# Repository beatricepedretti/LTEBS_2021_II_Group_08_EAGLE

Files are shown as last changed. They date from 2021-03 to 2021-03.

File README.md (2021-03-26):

# LTEBS_2021_II_Group_08_EAGLE

This repository contains the first project for the Electronic Technologies and Biosensors Laboratory course, part of the Biomedical Engineering MSc at Politecnico di Milano.
In this project we designed a schematic, a PCB and two custom components using Autodesk EAGLE. The aim of the work was to design a PCB embedding the PSoC 5LP micro-controller in order to evaluate its performance.

# PCB relevant info

- The PCB manufacturer is MDSrl and therefore we followed the rules explained on their website for PCB design (https://www.mdpcb.com/mddesignrules.html).
the 10mil minimum track width requested in the assignment specifications caused clearance errors at the pins of the MUX, therefore we routed this component using 8mil wires while still using 10mils wires everywhere else. This choice satisfies the manufacturer requirements which report 6mils as the minimum width for traces.
- We positioned the light sensor as far away as possible from the LED in order to avoid luminous interference given by the LED. We also tried to position the light sensor as isolated as possible from "tall" components in order to avoid shadows that could interfere with the sensor's measurements.
- We positioned the temperature sensor as far away as possible from the power supply in order to avoid interference given by possible heating of the power supply.
- For the copper pour we used isolation 8 that is the minimum allowed by the manufacturer
- We put jumpers on side of the board

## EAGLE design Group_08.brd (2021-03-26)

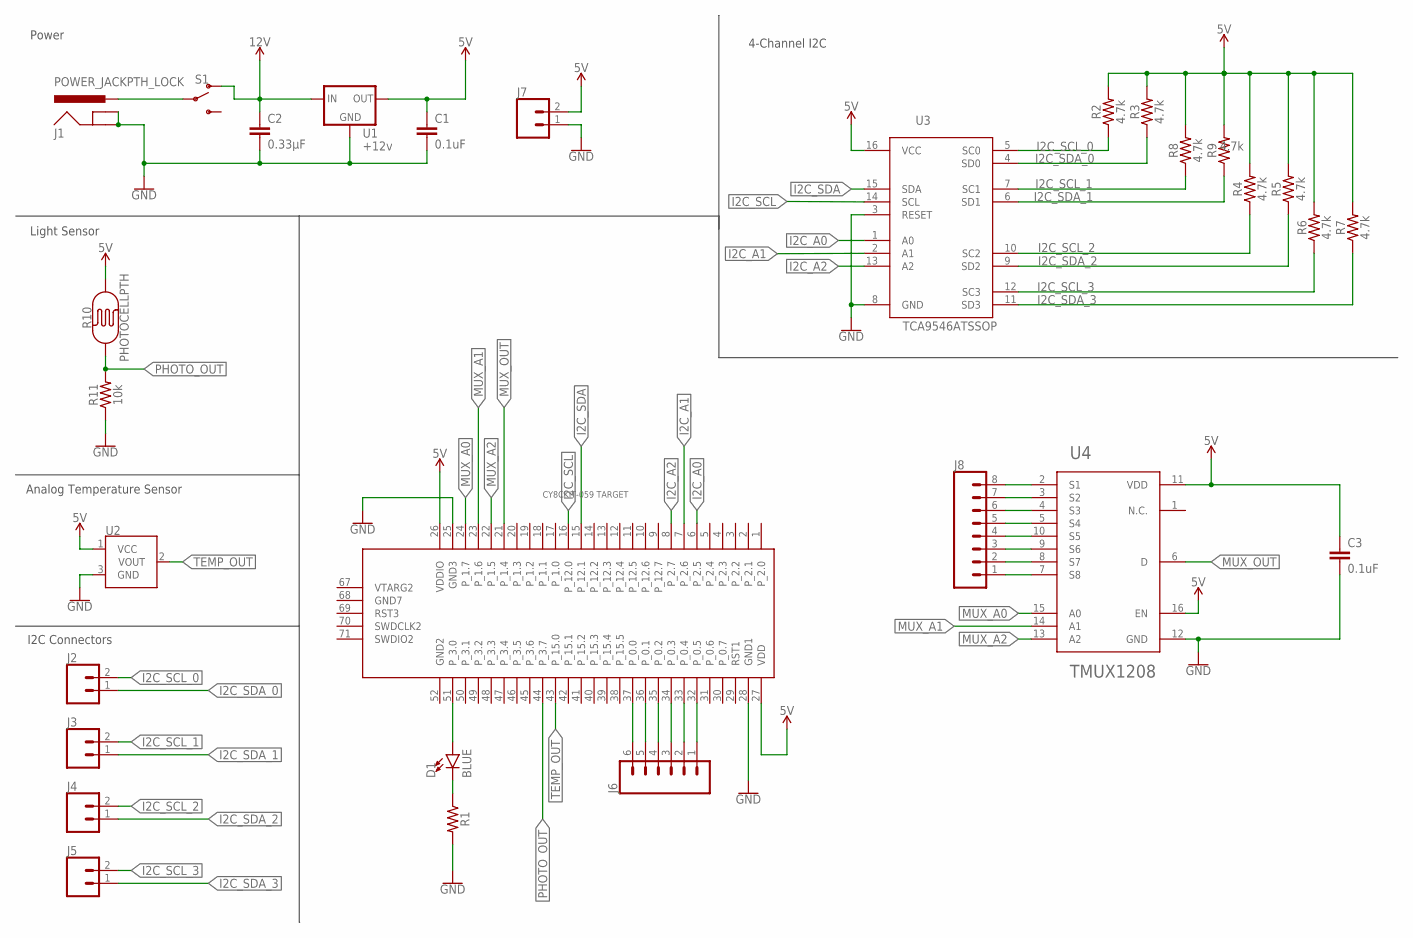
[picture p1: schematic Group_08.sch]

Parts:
C1, C3: 0.1uF; CAP-PTH-SMALL-KIT
C2: 0.33µF; 0805
CY8CKIT059-TARGET: CY8CKIT-059_TARGET
D1: BLUE; LED-1206
J1: POWER_JACKPTH_LOCK; POWER_JACK_PTH_LOCK
J2, J3, J4, J5, J7: CONN_02; 1X02
J6: CONN_06LOCK; 1X06_LOCK
J8: CONN_08LOCK; 1X08_LOCK
R1: RESISTORAXIAL-0.3; AXIAL-0.3
R2, R3, R4, R5, R6, R7, R8, R9: 4.7k; 0603
R10: PHOTOCELLPTH; PHOTOCELL
R11: 10k; 0603
S1: SWITCH-SPDT-PTH-11.6X4.0MM; SWITCH_SPDT_PTH_11.6X4.0MM
U1: +12v; TO-252
U2: TMP36GT9; TO-92
U3: TCA9546ATSSOP; TSSOP16
U4: TMUX1208; QFN16

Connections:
5V: C1.1, C3.1, CY8CKIT059-TARGET.26 (VDDIO), CY8CKIT059-TARGET.27 (VDD), J7.2, R2.2, R3.2, R4.2, R5.2, R6.2, R7.2, R8.2, R9.2, R10.2, U1.2 (OUT), U2.1 (VCC), U3.16 (VCC), U4.11 (VDD), U4.16 (EN)
12V: C2.1, S1.1 (O), U1.1 (IN)
GND: C1.2, C2.2, C3.2, CY8CKIT059-TARGET.25 (GND3), CY8CKIT059-TARGET.28 (GND1), J1.GND, J1.GNDBREAK, J7.1, R1.P$2 (2), R11.1, U1.3 (GND), U2.3 (GND), U3.3 (RESET), U3.8 (GND), U4.12 (GND)
I2C_A0: CY8CKIT059-TARGET.6 (P_2.5), U3.1 (A0)
I2C_A1: CY8CKIT059-TARGET.7 (P_2.6), U3.2 (A1)
I2C_A2: CY8CKIT059-TARGET.8 (P_2.7), U3.13 (A2)
I2C_SCL: CY8CKIT059-TARGET.16 (P_12.0), U3.14 (SCL)
I2C_SCL_0: J2.2, R2.1, U3.5 (SC0)
I2C_SCL_1: J3.2, R8.1, U3.7 (SC1)
I2C_SCL_2: J4.2, R4.1, U3.10 (SC2)
I2C_SCL_3: J5.2, R6.1, U3.12 (SC3)
I2C_SDA: CY8CKIT059-TARGET.15 (P_12.1), U3.15 (SDA)
I2C_SDA_0: J2.1, R3.1, U3.4 (SD0)
I2C_SDA_1: J3.1, R9.1, U3.6 (SD1)
I2C_SDA_2: J4.1, R5.1, U3.9 (SD2)
I2C_SDA_3: J5.1, R7.1, U3.11 (SD3)
MUX_A0: CY8CKIT059-TARGET.24 (P_1.7), U4.15 (A0)
MUX_A1: CY8CKIT059-TARGET.23 (P_1.6), U4.14 (A1)
MUX_A2: CY8CKIT059-TARGET.22 (P_1.5), U4.13 (A2)
MUX_OUT: CY8CKIT059-TARGET.21 (P_1.4), U4.6 (D)
unnamed: J1.PWR, S1.2
unnamed: J8.1, U4.7 (S8)
unnamed: J8.2, U4.8 (S7)
unnamed: J8.3, U4.9 (S6)
unnamed: J8.4, U4.10 (S5)
unnamed: J8.5, U4.5 (S4)
unnamed: J8.6, U4.4 (S3)
unnamed: J8.7, U4.3 (S2)
unnamed: J8.8, U4.2 (S1)
unnamed: CY8CKIT059-TARGET.37 (P_0.0), J6.6
unnamed: CY8CKIT059-TARGET.32 (P_0.5), J6.1
unnamed: CY8CKIT059-TARGET.33 (P_0.4), J6.2
unnamed: CY8CKIT059-TARGET.34 (P_0.3), J6.3
unnamed: CY8CKIT059-TARGET.35 (P_0.2), J6.4
unnamed: CY8CKIT059-TARGET.36 (P_0.1), J6.5
unnamed: D1.C, R1.P$1 (1)
unnamed: CY8CKIT059-TARGET.51 (P_3.0), D1.A
PHOTO_OUT: CY8CKIT059-TARGET.44 (P_3.7), R10.1, R11.2
TEMP_OUT: CY8CKIT059-TARGET.43 (P_15.0), U2.2 (VOUT)

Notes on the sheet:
Light Sensor
Analog Temperature Sensor
Power
4-Channel I2C
I2C Connectors

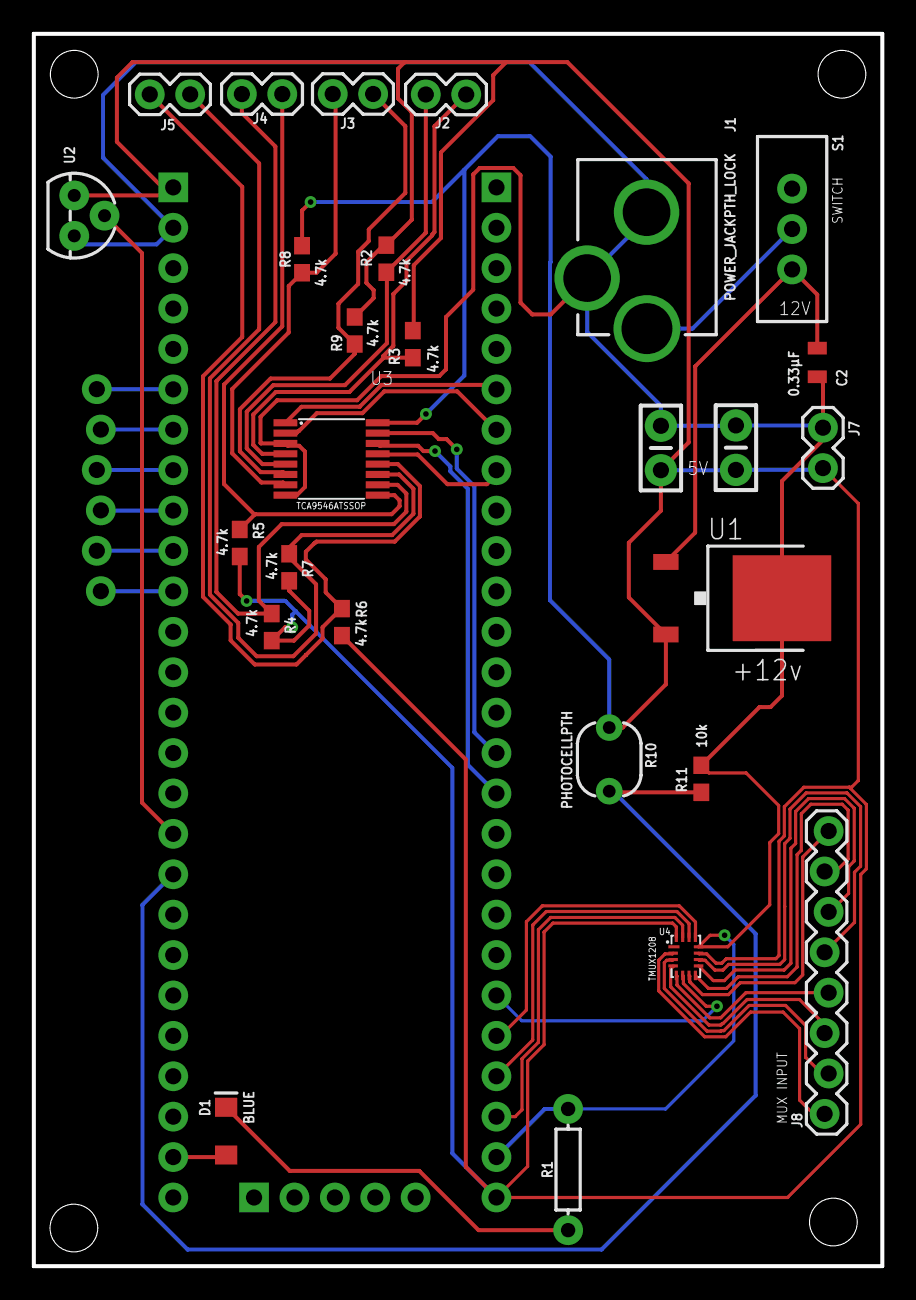
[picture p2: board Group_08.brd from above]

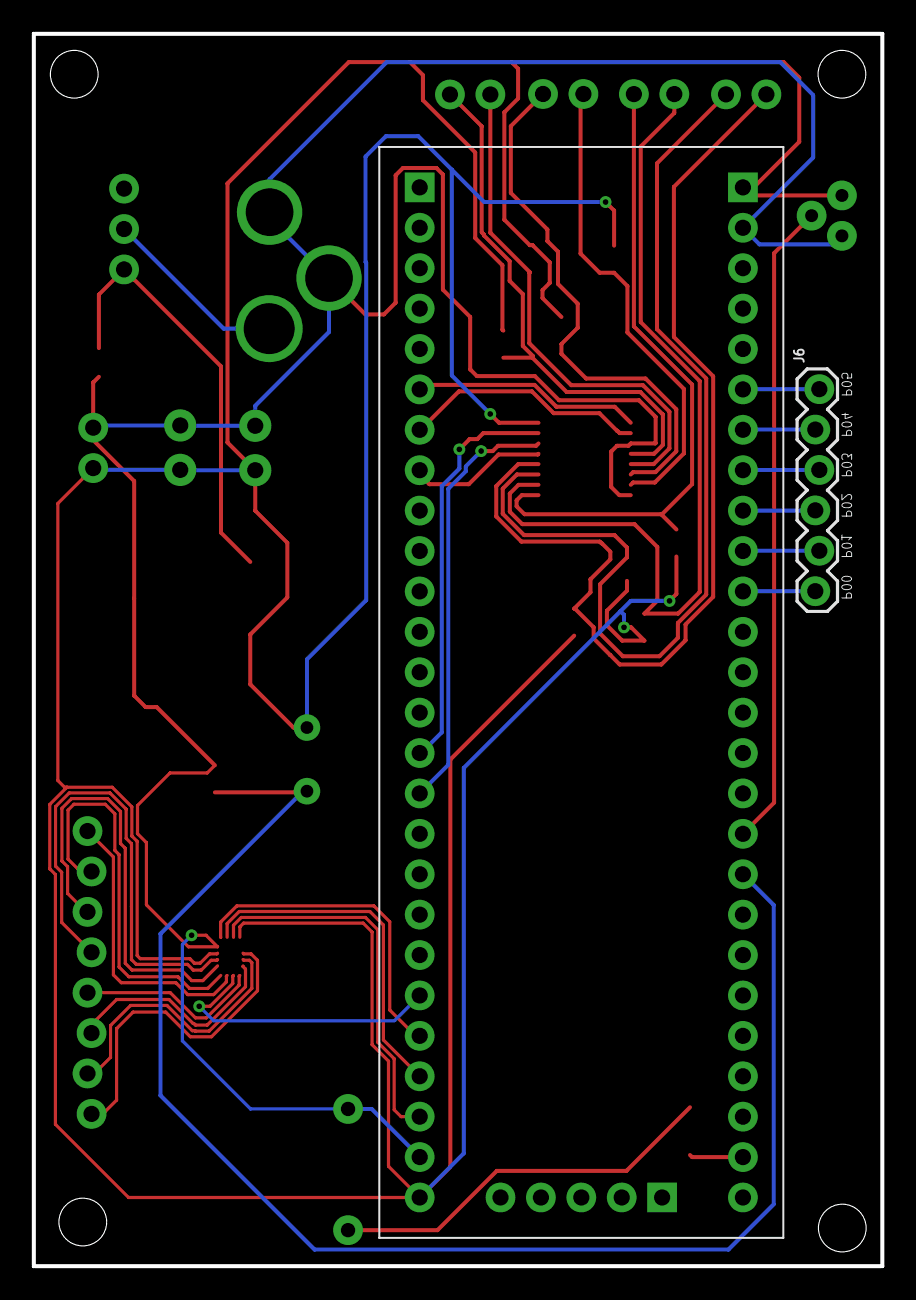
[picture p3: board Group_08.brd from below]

Board: 2 copper layers, 53.3 x 77.5 mm, 29 parts (2 on the bottom side), 39 nets.

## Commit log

2021-03-19 Added TMUX1208 device to general library ('Group_08_Library.lbr') for the moment. Saved the device in an additional library ('TMUX1208.lbr') for safety.
2021-03-19 Modified symbol to match reference schematics
2021-03-20 Adjusted TMUX1208 footprint
2021-03-22 Modified description headline of device
2021-03-22 First schematic prototype. Need to adjust nets
    [Group_08.sch]
2021-03-24 completed wiring
    [Group_08.sch]
2021-03-24 no changes, used correct username
    [Group_08.sch]
2021-03-24 Fixed wiring and did small aesthetic adjustments to library symbols
    [Group_08.sch]
2021-03-25 board with almoost all wiring done
    [Group_08.sch]
2021-03-25 real board file
    [Group_08.brd]
2021-03-25 Alternative version; 0 errors. Already done all wiring and copper pour. Need to add silkscreen and it's possible to reduce board size.
    [Group_08_alternative.brd, Group_08_alternative.sch]
2021-03-25 Mia versione della board
    [Group_08_Chiara.brd]
2021-03-25 added silkscreen
    [Group_08_Chiara.brd]
2021-03-25 Optimized board, added silkscreen. 0 errors after performing DCR.
    [Group_08_alternative.brd, Group_08_alternative.sch]
2021-03-25 Deleted original prototypes and updated file names
    [Group_08.brd, Group_08.sch]
2021-03-25 Deleted old files
    [Group_08_alternative.brd, Group_08_alternative.sch]
2021-03-26 minor adjustments at wire positioning and silkscreen
    [Group_08.brd]
2021-03-26 edited track width comments for clarity
2021-03-26 Updated schematics connections
    [Group_08.brd, Group_08.sch]
2021-03-26 Trying to make a smaller board
    [Group_08_2.brd, Group_08_2.sch]
2021-03-26 completed routing of smaller board
    [Group_08_2.brd]
2021-03-26 Adjustments to board file
    [Group_08_2.brd]
2021-03-26 Added stuff to silkscreen
    [Group_08_2.brd]
2021-03-26 Deleted redundant files
    [Group_08.brd, Group_08.sch]
2021-03-26 Renamed files correctly
    [Group_08.brd, Group_08.sch]
2021-03-26 Final version
    [Group_08.brd, Group_08.sch]

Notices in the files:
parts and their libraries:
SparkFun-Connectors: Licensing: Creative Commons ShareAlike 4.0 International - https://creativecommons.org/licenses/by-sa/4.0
